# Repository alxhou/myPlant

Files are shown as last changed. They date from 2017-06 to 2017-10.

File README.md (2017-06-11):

myPlant
=======

ESP8266 based soil moisture sensor WiFi enabled. Uses capacitive sensing inspired by the [I2C Moisture Sensor](https://github.com/Miceuz/i2c-moisture-sensor) project from Miceuz. Thanks for his source code. 

Repository Contents
-------------------

* **/Firmware** - Arduino source code (.ino, .h)
* **/Hardware** - All Eagle design files (.brd, .sch)

License Information
-------------------

This design is [OSHW](http://www.oshwa.org/definition/) and public domain but you buy me a beer if you use this and we meet someday ([Beerware license](http://en.wikipedia.org/wiki/Beerware)).

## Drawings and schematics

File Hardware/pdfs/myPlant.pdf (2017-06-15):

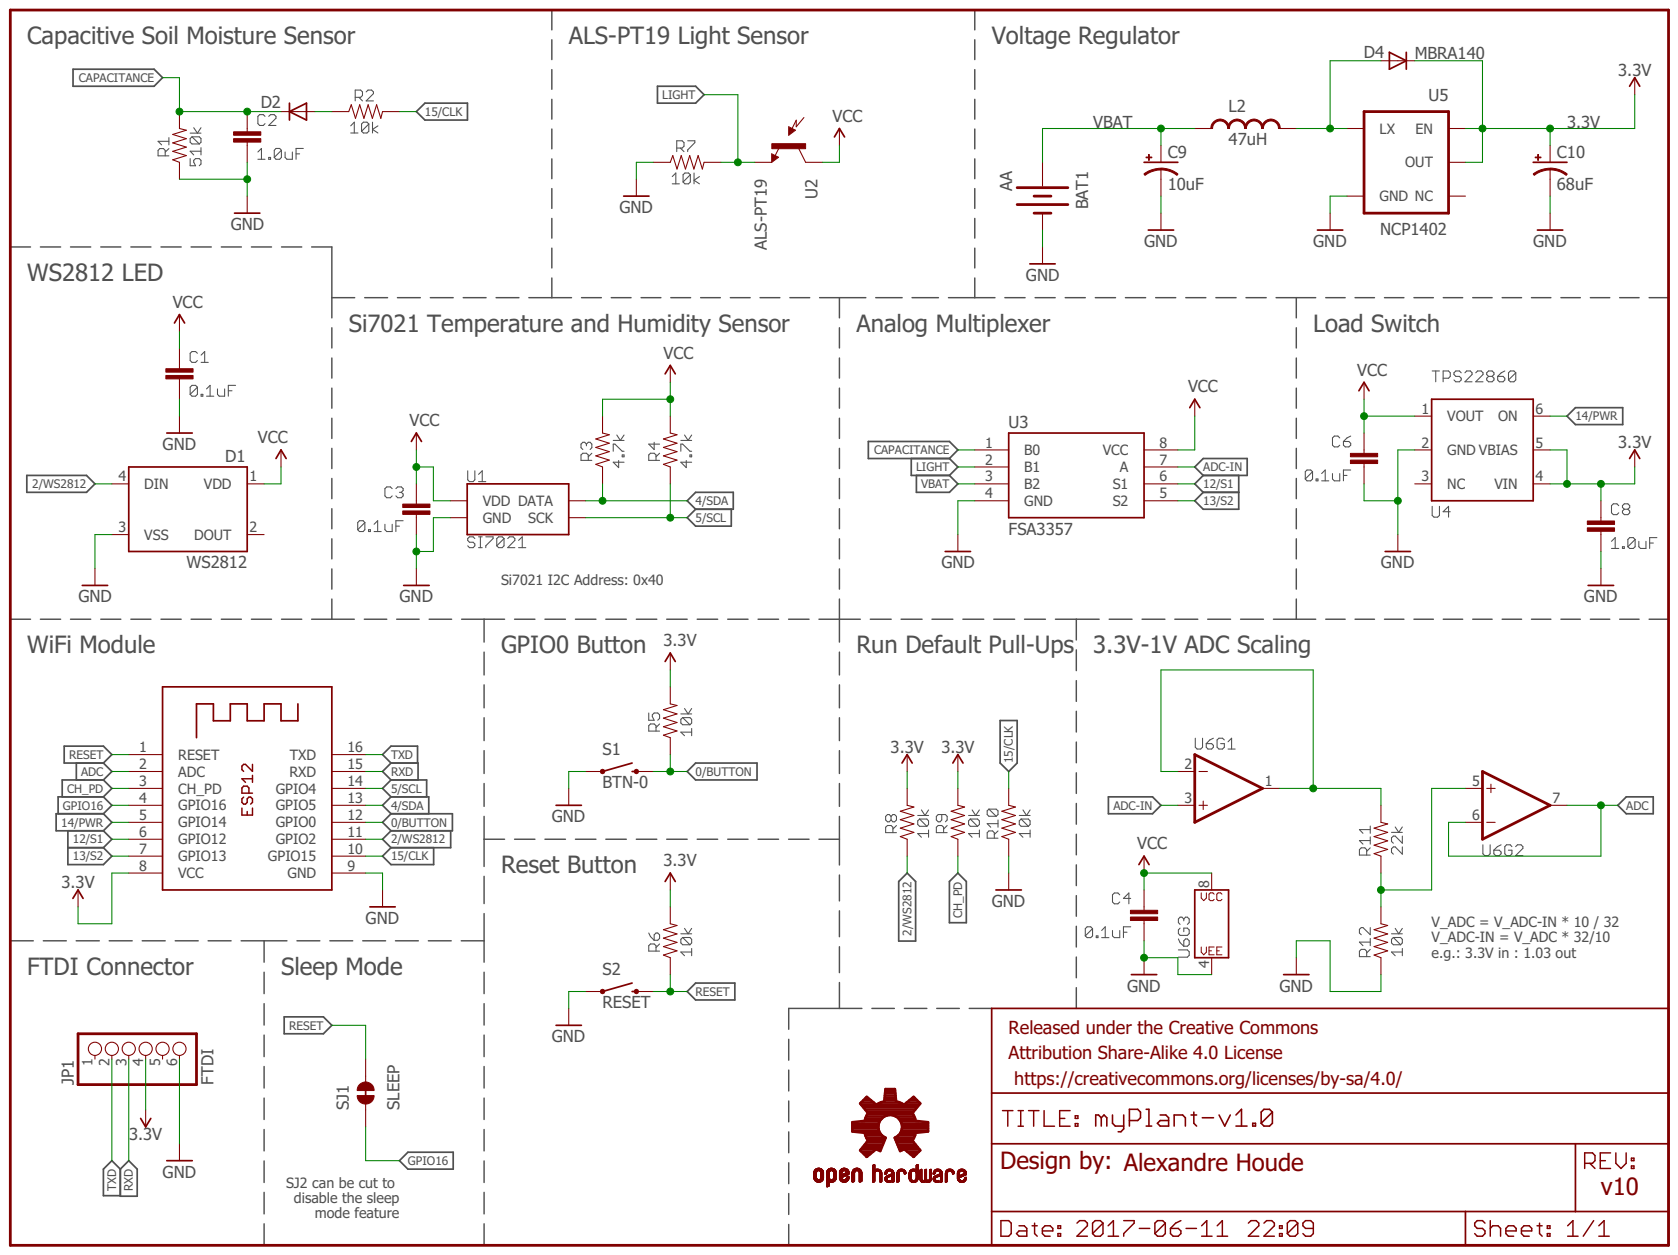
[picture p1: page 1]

Run Default Pull-Ups

Released under the Creative Commons
Attribution Share-Alike 4.0 License
https://creativecommons.org/licenses/by-sa/4.0/

SJ2 can be cut to disable the sleep mode feature

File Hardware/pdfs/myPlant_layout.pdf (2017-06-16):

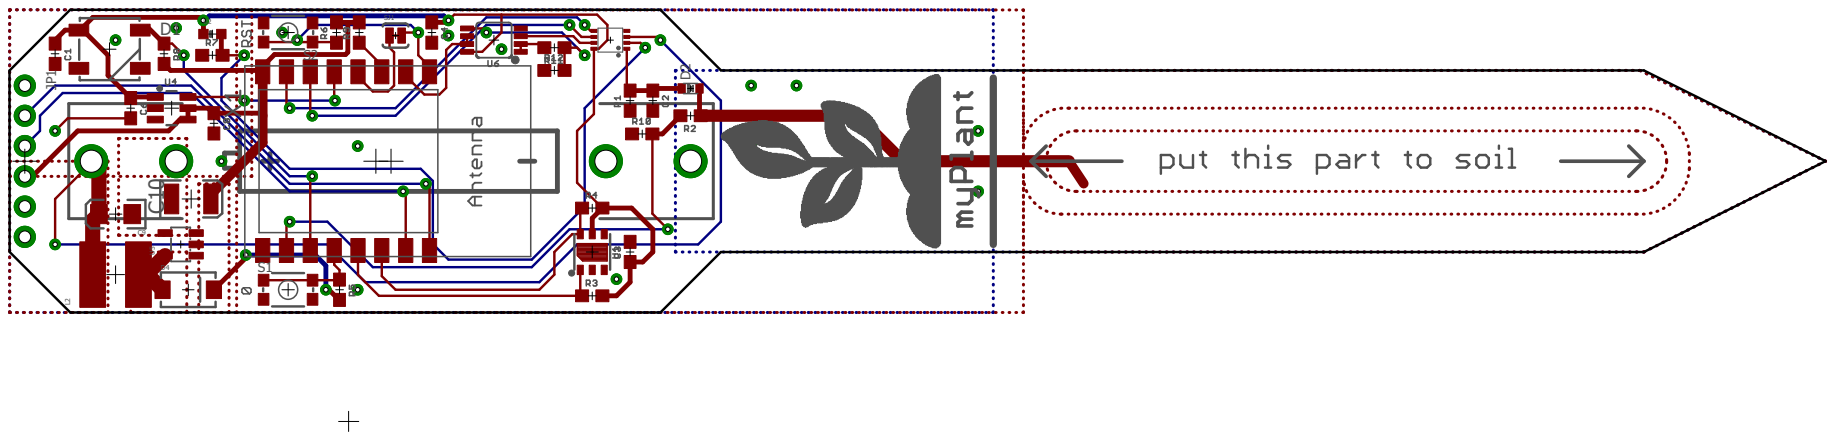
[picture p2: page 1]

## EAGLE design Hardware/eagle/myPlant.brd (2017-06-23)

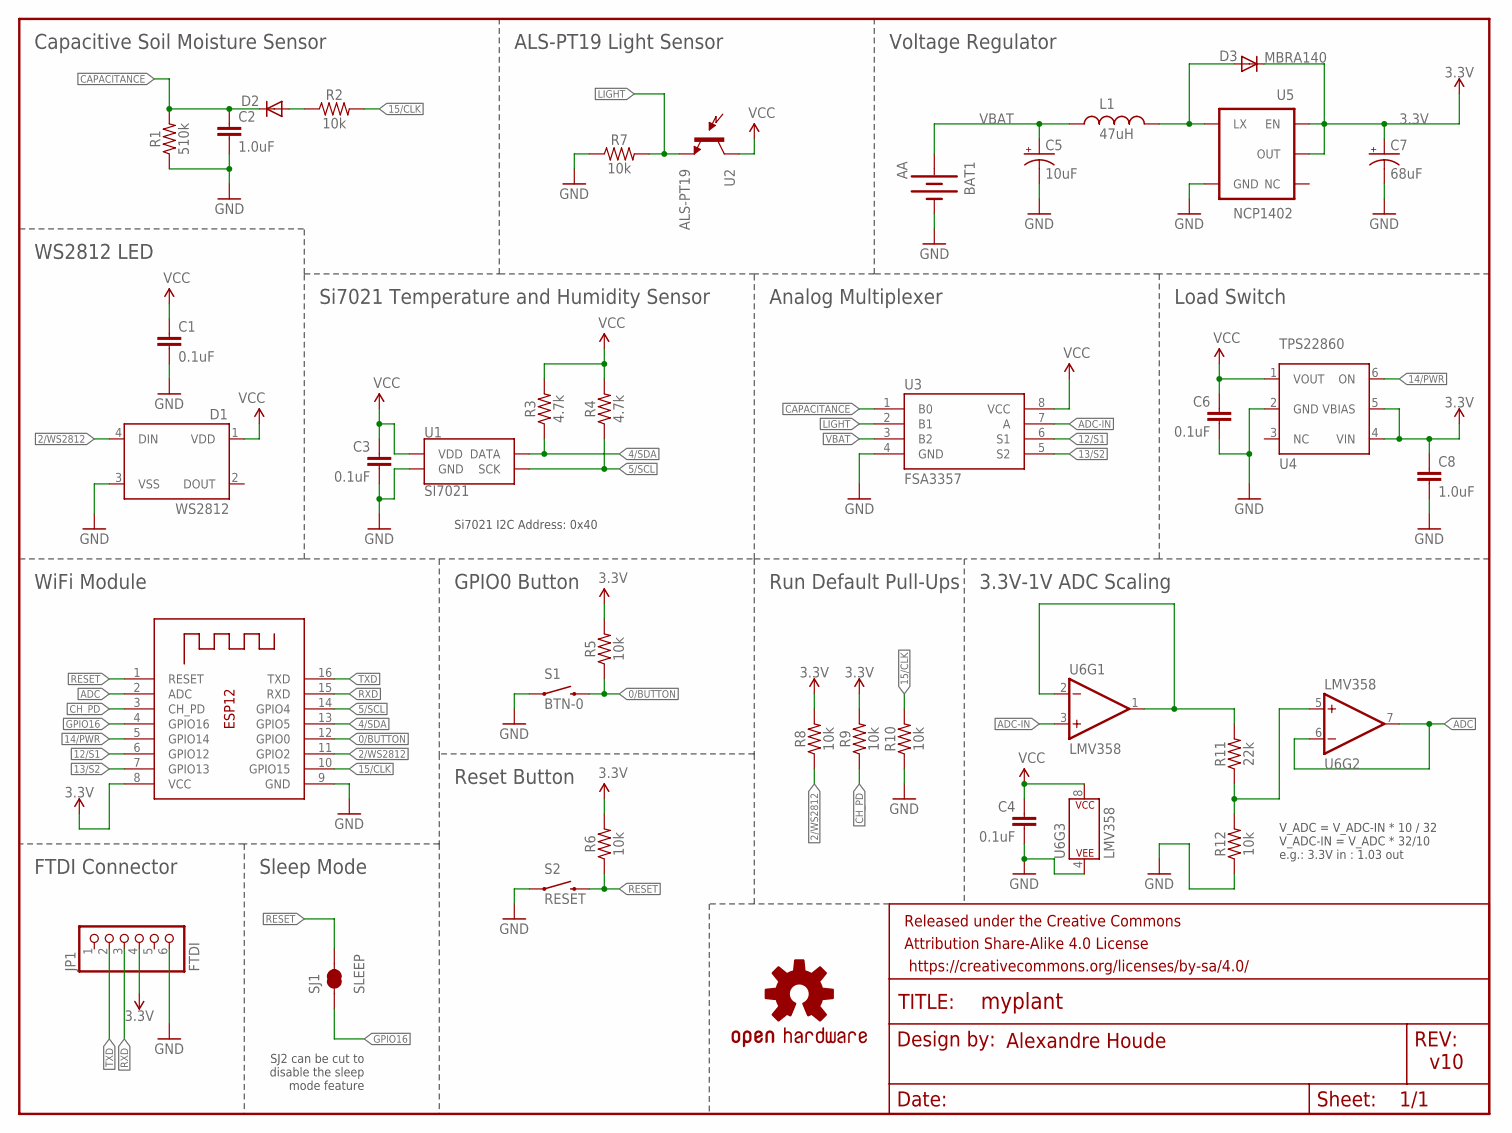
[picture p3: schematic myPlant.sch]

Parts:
BAT1: AA; BATTERY-AA-KIT
C1, C3, C4, C6: 0.1uF; 0603
C2, C8: 1.0uF; 0603
C5: 10uF; EIA3216
C7: 68uF; EIA3528
D1: WS2812; WS2812B
D2: DIODE-SCHOTTKY_; SOD-523
D3: MBRA140; SMA-DIODE
FRAME1: FRAME-LETTER; CREATIVE_COMMONS
JP1: FTDI; 1X06_ROUND_70
L1: 47uH; CR54
LOGO2: OSHW-LOGOS; OSHW-LOGO-S
R1: 510k; 0603
R2, R5, R6, R7, R8, R9, R10, R12: 10k; 0603
R3, R4: 4.7k; 0603
R11: 22k; 0603
S1: BTN-0; TACTILE_SWITCH_SMD_4.6X2.8MM
S2: RESET; TACTILE_SWITCH_SMD_4.6X2.8MM
SJ1: SLEEP; PAD-JUMPER-2-NC_BY_TRACE_YES_SILK
U1: SI7021; DFN-6-3X3-SI7021
U2: ALS-PT19
U3: FSA3357; US8
U4: TPS22860; SOT23-6
U5: NCP1402; SOT23-5
U6: LMV358; MSOP8
X1: ESP-12

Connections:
0/BUTTON: R5.1, S1.3 (2), S1.4 (2), X1.12 (GPIO0)
2/WS2812: D1.4 (DIN), R8.1, X1.11 (GPIO2)
3.3V: C7.A (+), C8.1, D3.C, JP1.4, R5.2, R6.2, R8.2, R9.2, U4.4 (VIN), U4.5 (VBIAS), U5.1 (EN), U5.2 (OUT), X1.8 (VCC)
4/SDA: R3.1, U1.DATA, X1.13 (GPIO5)
5/SCL: R4.1, U1.SCK, X1.14 (GPIO4)
12/S1: U3.6 (S1), X1.6 (GPIO12)
13/S2: U3.5 (S2), X1.7 (GPIO13)
14/PWR: U4.6 (ON), X1.5 (GPIO14)
15/CLK: R2.2, R10.2, X1.10 (GPIO15)
ADC: U6.6 (-IN), U6.7 (OUT), X1.2 (ADC)
ADC-IN: U3.7 (A), U6.3 (+IN)
CAPACITANCE: C2.1, D2.K (C), R1.2, U3.1 (B0)
CH_PD: R9.1, X1.3 (CH_PD)
GND: BAT1.GND@1 (-), C1.2, C2.2, C3.2, C4.2, C5.C (-), C6.2, C7.C (-), C8.2, D1.3 (VSS), JP1.6, R1.1, R7.1, R10.1, R12.1, S1.1, S1.2 (1), S2.1, S2.2 (1), U1.GND, U3.4 (GND), U4.2 (GND), U5.4 (GND), U6.4 (P$V-), X1.9 (GND)
GPIO16: SJ1.1, X1.4 (GPIO16)
LIGHT: R7.2, U2.E (E1), U3.2 (B1)
unnamed: D3.A, L1.P$2 (2), U5.5 (LX)
unnamed: R11.2, U6.1 (OUT), U6.2 (-IN)
unnamed: R11.1, R12.2, U6.5 (+IN)
RESET: R6.1, S2.3 (2), S2.4 (2), SJ1.2, X1.1 (RESET)
RXD: JP1.3, X1.15 (RXD)
TXD: JP1.2, X1.16 (TXD)
VBAT: BAT1.PWR@1 (+), C5.A (+), L1.P$1 (1), U3.3 (B2)
VCC: C1.1, C3.1, C4.1, C6.1, D1.1 (VDD), R3.2, R4.2, U1.VDD, U2.C (C1), U3.8 (VCC), U4.1 (VOUT), U6.8 (P$V+)
V_CAP: D2.A, R2.1

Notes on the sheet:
Si7021 I2C Address: 0x40
V_ADC = V_ADC-IN * 10 / 32 V_ADC-IN = V_ADC * 32/10 e.g.: 3.3V in : 1.03 out
Alexandre Houde
v10
Capacitive Soil Moisture Sensor
Voltage Regulator
Load Switch
3.3V-1V ADC Scaling
WiFi Module
WS2812 LED
ALS-PT19 Light Sensor
Analog Multiplexer
Si7021 Temperature and Humidity Sensor
GPIO0 Button
FTDI Connector
Run Default Pull-Ups
Sleep Mode
Reset Button
SJ2 can be cut to disable the sleep mode feature

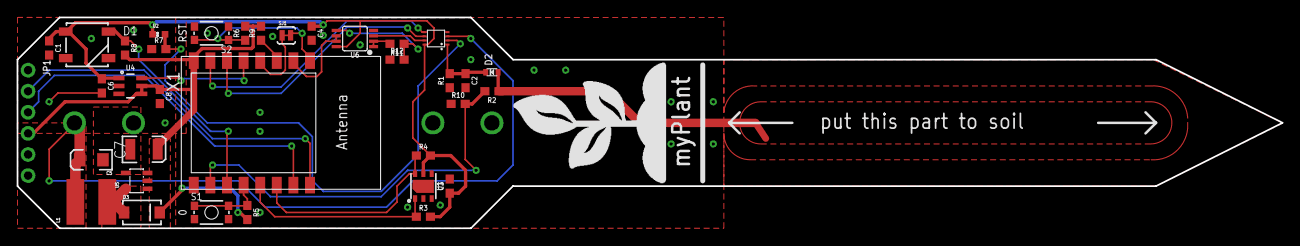
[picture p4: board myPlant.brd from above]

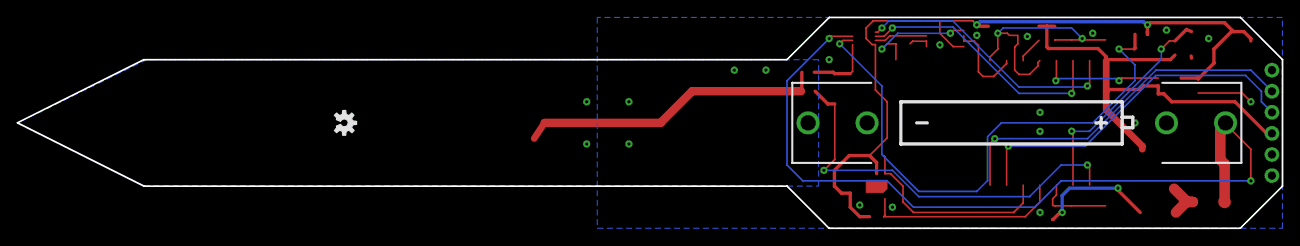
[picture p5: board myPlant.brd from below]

Board: 2 copper layers, 152.4 x 25.4 mm, 38 parts (2 on the bottom side), 25 nets.

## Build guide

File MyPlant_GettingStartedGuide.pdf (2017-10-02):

Étape Configuration

1. Mettre l’interrupteur a ON

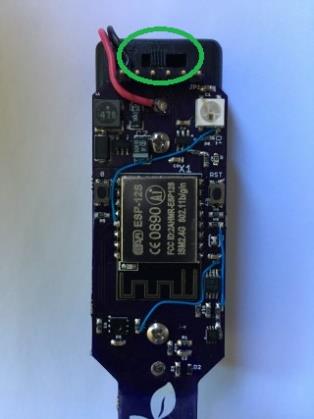
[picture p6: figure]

2. Appuyer sur le bouton 0 environ 10 secondes pour réinitialiser la configuration

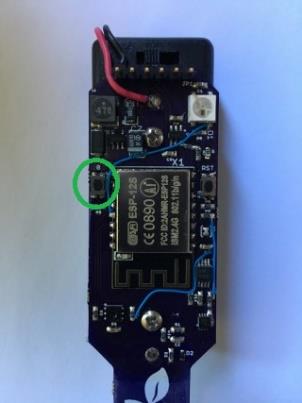
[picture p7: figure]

3. La DEL devrait clignoter de couleur cyan pour indiquer que le module est en attende de configuration.
4. Se connecter au WiFi du module : Blynk myPlant
5. Aller sur la page web de config : http://my-plant.cc/
6. Entrer la configuration et appuyer sur Apply.

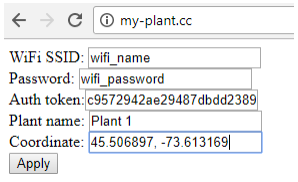
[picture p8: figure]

Le Auth token à utiliser est d9ec6d54ef9c446bac7dbfa0b517a887

Étape Utilisation

1. Télécharger l’application Blynk

IOS : https://itunes.apple.com/us/app/blynk-control-arduinoraspberry/id808760481?ls=1&mt=8 (https://itunes.apple.com/us/app/blynk-control-arduino-raspberry/id808760481?ls=1&mt=8)

Android : https://play.google.com/store/apps/details?id=cc.blynk

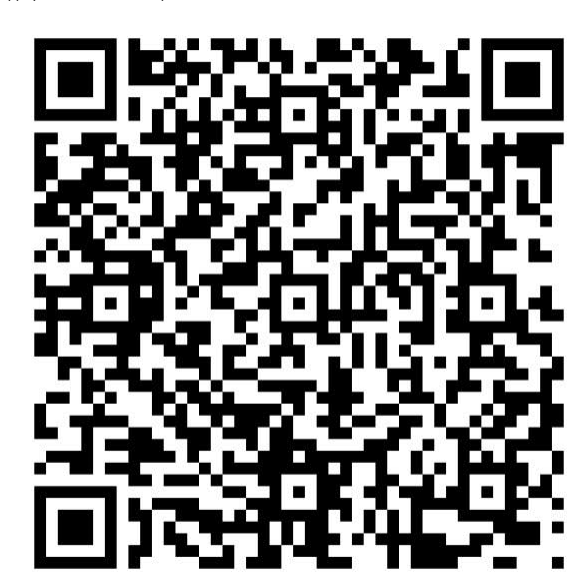
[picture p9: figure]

2. Appuyez sur l'icône QR et pointez la caméra vers le code ci-dessous

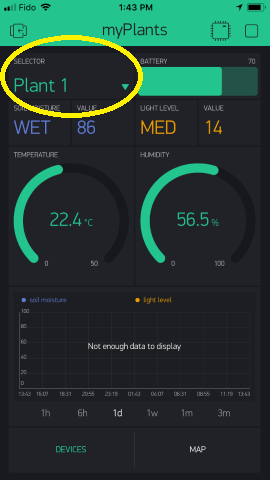
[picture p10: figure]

3. L’application devrait apparaitre, le sélecteur permet de choisir le module qu’on veut lire.

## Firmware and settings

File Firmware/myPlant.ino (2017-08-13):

/*************************************************************
  myPlant allows plants to ask for human help:
  https://github.com/alxhou/myPlant

  program by Alexandre Houde with additional code from various public examples.

  Based on Blynk Demo App:
  http://www.blynk.io/demo/

 *************************************************************/

#define APP_DEBUG        // Comment this out to disable debug prints

#define BLYNK_PRINT Serial
#include <BlynkSimpleEsp8266.h>
#include "BlynkProvisioning.h"
#include "Adafruit_Si7021.h"

// Alert messages
#define URGENT_WATER ": URGENT! Water me! :O "
#define WATER ": Water me please. :( "
#define THANK_YOU ": Thank you for watering me! :) "
#define OVER_WATERED ": You over watered me. "
#define UNDER_WATERED ": You didn't water me enough. "
#define OK ": I'm fine. "
#define BATTERY ": Change my battery please. "
#define THANK_BATT ": Thank you for the new battery! :) "

//tracks the state to avoid erroneously repeated tweets
#define BATTERY_LOW 4
#define URGENT_SENT 3
#define WATER_SENT 2
#define MOISTURE_OK 1

#define HYSTERESIS 25 // stabilization value http://en.wikipedia.org/wiki/Hysteresis

#define BLYNK_GREEN     "#23C48E"
#define BLYNK_BLUE      "#04C0F8"
#define BLYNK_YELLOW    "#ED9D00"
#define BLYNK_RED       "#D3435C"
#define BLYNK_DARK_BLUE "#5F7CD8"

static int state = MOISTURE_OK; // tracks which messages have been sent
static int counter = 0;
static int power = 14;
static int sleepTimeS = 10;
static int wateringThreshold = 20;
static int isParametersReceived = 0;

static bool isNotificationSent = true;
static bool isDataSent = false;


Adafruit_Si7021 sensor = Adafruit_Si7021();


void setup() {
  Serial.begin(115200);

  sensor_init();
  sensor_read();


  /**************************************************************
   *
   * Workflow to connect the device to WiFi network.
   * Here is how it works:
   * 1. At the first start hardware acts as an Access Point and
   *    broadcasts it's own WiFi.
   * 2. myPlant smartphone app connects to this Access Point
   * 3. myPlant smartphone app request new Auth Token and passes
   *    it together with user's WiFi SSID and password
   * 4. Hardware saves this information to EEPROM
   * 5. Hardware reboots and now connects to user's WiFi Network
   * 6. Hardware connects to Blynk Cloud and is ready to work with app
   *
   * Next time the hardware reboots, it will use the same configuration
   * to connect. User can RESET the board and re-initiate provisioning
   *
   * Explore the Settings.h for parameters
   * Read the documentation for more info: http://
   *
   **************************************************************/

  BlynkProvisioning.begin();
}

void loop() {
  // This handles the network and cloud connection
  BlynkProvisioning.run();

  // Send sensors value to cloud when ready
  if (!isDataSent &&(isParametersReceived == 5) && (BlynkState::is(MODE_RUNNING) || BlynkState::is(MODE_THIRSTY))) {
    send_sensor_value();
    send_alert();
    send_map_value();
    isDataSent = true;

    if (state == BATTERY_LOW) {
      BlynkState::set(MODE_BATTERY);
    }
    else if (state > MOISTURE_OK) {
      BlynkState::set(MODE_THIRSTY);
    }
    else {
      digitalWrite(power, LOW);
      DEBUG_PRINT("Device in sleep mode");
      ESP.deepSleep(sleepTimeS * 1000000);
    } 
  }

  if (isDataSent && BlynkState::is(MODE_THIRSTY)) {
    soil_humidity_check();
    send_alert();

    if (state == MOISTURE_OK) {
      BlynkState::set(MODE_WATER);
      delay(5000);
      digitalWrite(power, LOW);
      DEBUG_PRINT("Device in sleep mode");
      ESP.deepSleep(1 * 1000000);
    }

    // Put device in sleep mode after 5min without being watered to save battery power
    if (millis() > 300000) {
      digitalWrite(power, LOW);
      DEBUG_PRINT("Device in sleep mode");
      ESP.deepSleep(sleepTimeS * 1000000);
    }
  }
  if (isDataSent && BlynkState::is(MODE_BATTERY)) { 
    // Put device in sleep mode after 5min without being watered to save battery power
    if (millis() > 300000) {
      digitalWrite(power, LOW);
      DEBUG_PRINT("Device in sleep mode");
      ESP.deepSleep(sleepTimeS * 1000000);
    }
  }
}


/**************************************************************
 *
 *              myPlant App code
 *
 * The following code manage plant monitoring system
 *
 **************************************************************/

static int s1 = 12;
static int s2 = 13;
static int clk = 15;

static int sensorLight = 0;
static int sensorBattery = 0;
static int sensorSoilMoisture = 0;
static float sensorAirHumidity = 0.0;
static float sensorAirTemperature = 0.0;

WidgetMap myMap(V0);
int mapIndex = 1;

String alertMessage = "OK";

// Calibration factors
static int soilMoistureOffset = 0;
static float soilMoistureGain = 1.0;
const int lightOffset = -46;
const float lightGain = 0.104;
const int batteryOffset = -630;
const float batteryGain = 0.4;

// Getting data from "soil offset" step setting
BLYNK_WRITE(V5) {
  soilMoistureOffset = param.asInt() * -1;
  DEBUG_PRINT(String("Soil moisture offset: ") + soilMoistureOffset);
  isParametersReceived += 1;
}

// Getting data from "soil gain" step setting
BLYNK_WRITE(V6) {
  soilMoistureGain = param.asInt() / 100.0;
  DEBUG_PRINT(String("Soil moisture Gain: ") + soilMoistureGain);
  isParametersReceived += 1;
}

// Getting data from "Refresh Rate" step setting
BLYNK_WRITE(V10) {
  sleepTimeS = param.asInt() * 60;
  if (sleepTimeS == 0) {
    sleepTimeS = 10;
  } 
  DEBUG_PRINT(String("Refresh rate: ") + sleepTimeS);
  isParametersReceived += 1;
}

// Getting data from "Watering threshold" step setting
BLYNK_WRITE(V11) {
  wateringThreshold = param.asInt();
  DEBUG_PRINT(String("Watering threshold: ") + wateringThreshold);
  isParametersReceived += 1;
}

// Getting data from "map index" step setting
BLYNK_WRITE(V12) {
  mapIndex = param.asInt();
  DEBUG_PRINT(String("Map index: ") + mapIndex);
  isParametersReceived += 1;
}

// When device starts ->
//   sync app parameters
BLYNK_CONNECTED() {
  Blynk.syncVirtual(V5, V6, V10, V11, V12);
}


void sensor_init() {
  DEBUG_PRINT("Init sensors");
  pinMode(power, OUTPUT);
  pinMode(s1, OUTPUT);
  pinMode(s2, OUTPUT);
  
  digitalWrite(power, HIGH);

  analogWriteFreq(40000);
  analogWrite(clk, 100);

  delay(200);

  sensor.begin();
}


void sensor_read() {
  DEBUG_PRINT("Read sensor");
  
  // Soil Moisture
  digitalWrite(s1, HIGH);
  digitalWrite(s2, LOW);
  delay(100);
  sensorSoilMoisture = 1023 - analogRead(A0);
  DEBUG_PRINT("Soil Moisture RAW: " + String(sensorSoilMoisture));
  //sensorSoilMoisture = (sensorSoilMoisture + soilMoistureOffset)*soilMoistureGain;
  //DEBUG_PRINT("Soil Moisture: " + String(sensorSoilMoisture));
   
  // Light level
  digitalWrite(s1, LOW);
  digitalWrite(s2, HIGH);
  delay(100);
  sensorLight = analogRead(A0);
  DEBUG_PRINT("Light level RAW: " + String(sensorLight));
  sensorLight = (sensorLight + lightOffset)*lightGain;
  DEBUG_PRINT("Light level: " + String(sensorSoilMoisture));

  // Battery level
  digitalWrite(s1, HIGH);
  digitalWrite(s2, HIGH);
  delay(100);
  sensorBattery = analogRead(A0);
  DEBUG_PRINT("Battery level RAW: " + String(sensorBattery));
  sensorBattery = (sensorBattery + batteryOffset)*batteryGain;
  DEBUG_PRINT("Battery level: " + String(sensorBattery));

  // Air humidity
  sensorAirHumidity = sensor.readHumidity();
  DEBUG_PRINT("Air humidity: " + String(sensorAirHumidity));

  // Air temperature
  sensorAirTemperature = sensor.readTemperature();
  DEBUG_PRINT("Air temperature: " + String(sensorAirTemperature));

  // Init rgb led
  indicator.initLED();

  // Unselect sensors
  digitalWrite(s1, LOW);
  digitalWrite(s2, LOW);
}


void send_sensor_value() {
  DEBUG_PRINT("Send sensors values to cloud");

  Blynk.virtualWrite(V3, sensorAirTemperature);
  Blynk.virtualWrite(V4, sensorAirHumidity);

  // Soil moisture
  sensorSoilMoisture = (sensorSoilMoisture + soilMoistureOffset)*soilMoistureGain;
  if (sensorSoilMoisture < 30) {
    Blynk.virtualWrite(V1, "DRY");
  } else if (sensorSoilMoisture > 80) {
    Blynk.virtualWrite(V1, "WET");
  } else {
    Blynk.virtualWrite(V1, "MOIST");
  }
  Blynk.virtualWrite(V7, sensorSoilMoisture);

  // Light level
  if (sensorLight < 10) {
    Blynk.virtualWrite(V2, "LOW");
  } else if (sensorLight > 80) {
    Blynk.virtualWrite(V2, "HIGH");
  } else {
    Blynk.virtualWrite(V2, "MED");
  }
  Blynk.virtualWrite(V8, sensorLight);

  if (sensorBattery > 100) {
    sensorBattery = 100;
  }

  // Battery level
  if (sensorBattery < 10) {
    Blynk.setProperty(V9, "color", BLYNK_RED);
  } else {
    Blynk.setProperty(V9, "color", BLYNK_GREEN);
  }
  
  Blynk.virtualWrite(V9, sensorBattery); 
}


void soil_humidity_check() {
  DEBUG_PRINT("Check soil humidity");
  
  // Soil Moisture
  digitalWrite(s1, HIGH);
  digitalWrite(s2, LOW);
  delay(100);
  sensorSoilMoisture = 1023 - analogRead(A0);
  DEBUG_PRINT("Soil Moisture RAW: " + String(sensorSoilMoisture));
  sensorSoilMoisture = (sensorSoilMoisture + soilMoistureOffset)*soilMoistureGain;
  DEBUG_PRINT("Soil Moisture: " + String(sensorSoilMoisture));
   
  // Unselect sensors
  digitalWrite(s1, LOW);
  digitalWrite(s2, LOW);

   delay(1000);
}


void send_map_value() {
  String latVal = getValue(configStore.plantCoordinate, ',', 0);
  String lonVal = getValue(configStore.plantCoordinate, ',', 1);
  float lat = latVal.toFloat();
  float lon = lonVal.toFloat();

  if (state == MOISTURE_OK) {
    alertMessage = OK;
  }

  DEBUG_PRINT("Send Map value @ " + String(lat) + " and " + String(lon));
  myMap.location(mapIndex, lat, lon, String(configStore.plantName) + alertMessage); 
}


void send_alert() {
  state = configStore.state;
  counter = configStore.counter;
  DEBUG_PRINT("State: " + String(state) + " & Counter: " + String(counter));

  // Watering alert
  if ((sensorSoilMoisture  < (wateringThreshold - 10)) && (state < URGENT_SENT)) {
    DEBUG_PRINT("URGENT tweet");
    alertMessage = URGENT_WATER;
    state = URGENT_SENT; // remember this message
    isNotificationSent = false;
  }
  else if  ((sensorSoilMoisture < wateringThreshold) && (state < WATER_SENT)) {
    DEBUG_PRINT("WATER tweet");
    alertMessage = WATER;
    state = WATER_SENT; // remember this message
    isNotificationSent = false;
  }
  else if ((sensorSoilMoisture > (wateringThreshold + HYSTERESIS)) && (state > MOISTURE_OK) && (state < BATTERY_LOW)) {
    DEBUG_PRINT("OK tweet");
    alertMessage = THANK_YOU;
    state = MOISTURE_OK; // reset to messages not yet sent state
    isNotificationSent = false;
  }
  else {
    // Battery alert
    if ((sensorBattery < 10) && (state == MOISTURE_OK)) {
      DEBUG_PRINT("BATTERY LOW tweet");
      alertMessage = BATTERY;
      state = BATTERY_LOW; // remember this message
     isNotificationSent = false;
   }
    else if ((sensorBattery > 30) && (state == BATTERY_LOW)) {
      DEBUG_PRINT("BATTERY OK tweet");
      alertMessage = THANK_BATT;
      state = MOISTURE_OK; // reset to messages not yet sent state
      isNotificationSent = false;
    }
  }
  
  if (isNotificationSent == false) {
    Blynk.tweet(String(configStore.plantName) + String(alertMessage) + " [ID-" + String(counter) + "] ");
    Blynk.notify(String(configStore.plantName) + String(alertMessage));
    isNotificationSent = true;
    DEBUG_PRINT("Notification sent");
    counter += 1;
    configStore.state = state;
    configStore.counter = counter;
    config_save();
  }
}


String getValue(String data, char separator, int index)
{
    int found = 0;
    int strIndex[] = { 0, -1 };
    int maxIndex = data.length() - 1;

    for (int i = 0; i <= maxIndex && found <= index; i++) {
        if (data.charAt(i) == separator || i == maxIndex) {
            found++;
            strIndex[0] = strIndex[1] + 1;
            strIndex[1] = (i == maxIndex) ? i+1 : i;
        }
    }
    return found > index ? data.substring(strIndex[0], strIndex[1]) : "";
}

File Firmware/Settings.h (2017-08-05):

/*
 * General options
 */

#define BOARD_FIRMWARE_VERSION        "1.0.0"
#define BOARD_HARDWARE_VERSION        "1.0.0"

#define BOARD_NAME                    "My Plant"           // Name of your product. Should match App Export request info.
#define BOARD_VENDOR                  "Blynk"              // Name of your company. Should match App Export request info.

#define PRODUCT_WIFI_SSID             "Blynk myPlant"      // Name of the device, to be displayed during configuration. Should match export request info.
#define BOARD_CONFIG_AP_URL           "my-plant.cc"        // Config page will be available in a browser at 'http://my-plant.cc/'

/*
 * Board configuration
 */

#define BOARD_BUTTON_PIN            0                     // Pin where user button is attached
#define BOARD_BUTTON_ACTIVE_LOW     true                  // true if button is "active-low"

//#define BOARD_LED_PIN              2                    // Set LED pin - if you have a single-color LED attached
//#define BOARD_LED_PIN_R           15                    // Set R,G,B pins - if your LED is PWM RGB 
//#define BOARD_LED_PIN_G           12
//#define BOARD_LED_PIN_B           13
#define BOARD_LED_PIN_WS2812        4                     // Set if your LED is WS2812 RGB
//#define BOARD_LED_INVERSE         false                 // true, if you need to inverse LED signal
#define BOARD_RGB_BRIGHTNESS        32                    // 0..255 brightness control



/*
 * Advanced options
 */

#define BUTTON_HOLD_TIME_INDICATION   3000
#define BUTTON_HOLD_TIME_ACTION       10000

#define BOARD_PWM_MAX                 1023

#define WIFI_NET_CONNECT_TIMEOUT      30000
#define WIFI_CLOUD_CONNECT_TIMEOUT    15000
#define WIFI_AP_CONFIG_PORT           80
#define WIFI_AP_IP                    IPAddress(192, 168, 4, 1)
#define WIFI_AP_Subnet                IPAddress(255, 255, 255, 0)
//#define WIFI_CAPTIVE_PORTAL_ENABLE

#define USE_TICKER
//#define USE_TIMER_ONE
//#define USE_TIMER_THREE

#if defined(APP_DEBUG)
  #define DEBUG_PRINT(...) BLYNK_LOG1(__VA_ARGS__)
#else
  #define DEBUG_PRINT(...)
#endif

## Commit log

2017-06-11 Added load switch
    [myPlant.brd, myPlant.sch]
2017-06-15 Done preliminary pcb placement
    [myPlant.brd, myPlant.sch]
2017-06-16 Complete PCB layout
    [myPlant.brd]
2017-06-23 Change file location
    [myPlant.brd]
2017-06-23 Corrected DRC errors
    [myPlant.brd, myPlant.sch]
2017-07-11 Implemented analog and digital sensors
2017-07-19 Implemented RGB led and soil moisture sensor calibration

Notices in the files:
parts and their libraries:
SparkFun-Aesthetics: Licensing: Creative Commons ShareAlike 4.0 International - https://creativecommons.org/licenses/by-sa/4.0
